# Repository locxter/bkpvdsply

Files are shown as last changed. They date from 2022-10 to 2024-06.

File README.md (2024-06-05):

# bkpvdsply

## Overview

> This project is **DEPRECATED**, therefore might not be on par with my current coding standards and will not receive any updates now or in the future. Please use my [next generation version (BikeBeamer)](https://github.com/BikeBeamer/BikeBeamer) instead.

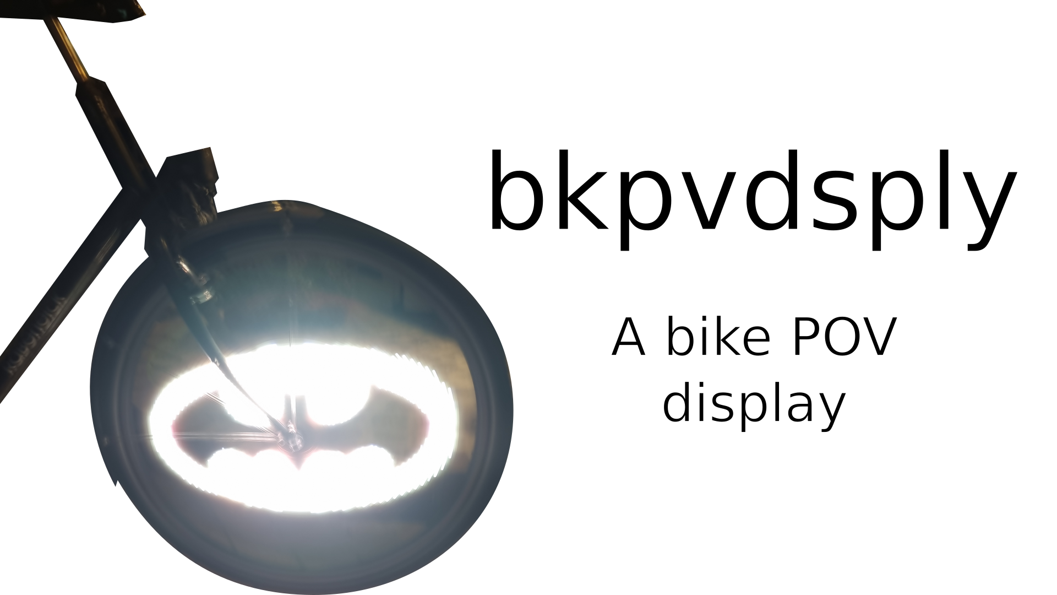
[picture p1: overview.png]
Overview image


This is a bike POV display using readily available parts.

## Dependencies

I generally try to minimize dependencies, but I'm a one man crew and can therefore only support Debian-based Linux distributions as I'm running one myself. Anyway, you need to have the following packages installed for everything to work properly:

- Arduino IDE as a way to compile the Arduino code. Install it with `sudo apt install arduino`.
- Arduino ESP32 LittleFS uploader for uploading the data. Install it via the [installation guide](https://github.com/lorol/arduino-esp32fs-plugin).
- Adafruit NeoPixel library for controlling the LEDs. Install it via the integrated library manager.
- MPU6050_tockn library for communicating with the gyroscope. Install it via the integrated library manager.

## How to build it

This project is relatively straight forward as it mainly consists of an ESP32, an LED strip that's slit into four segments, a MPU-6050 and an USB power bank all housed in 3D printed enclosures and mounted with cable ties. For inspiration take a look at the mounting and assembly image as well as wiring diagram down below:

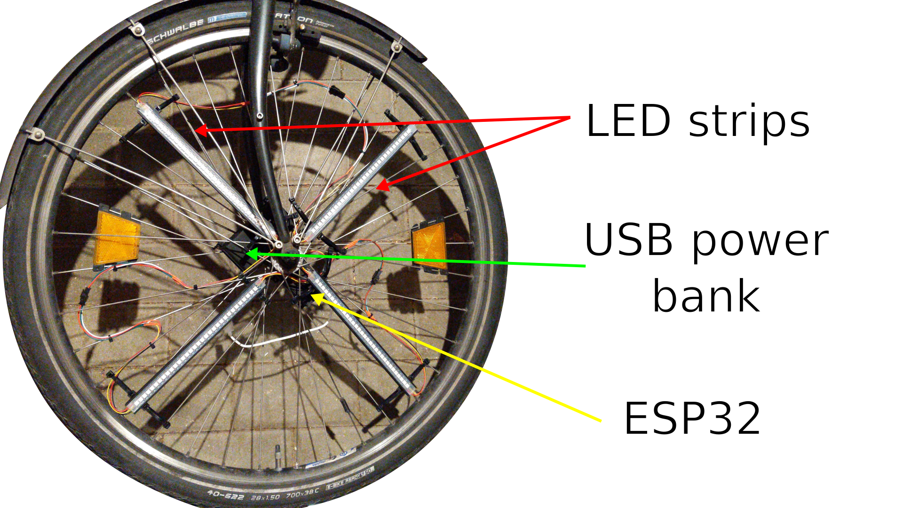
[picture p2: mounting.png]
Mounting image


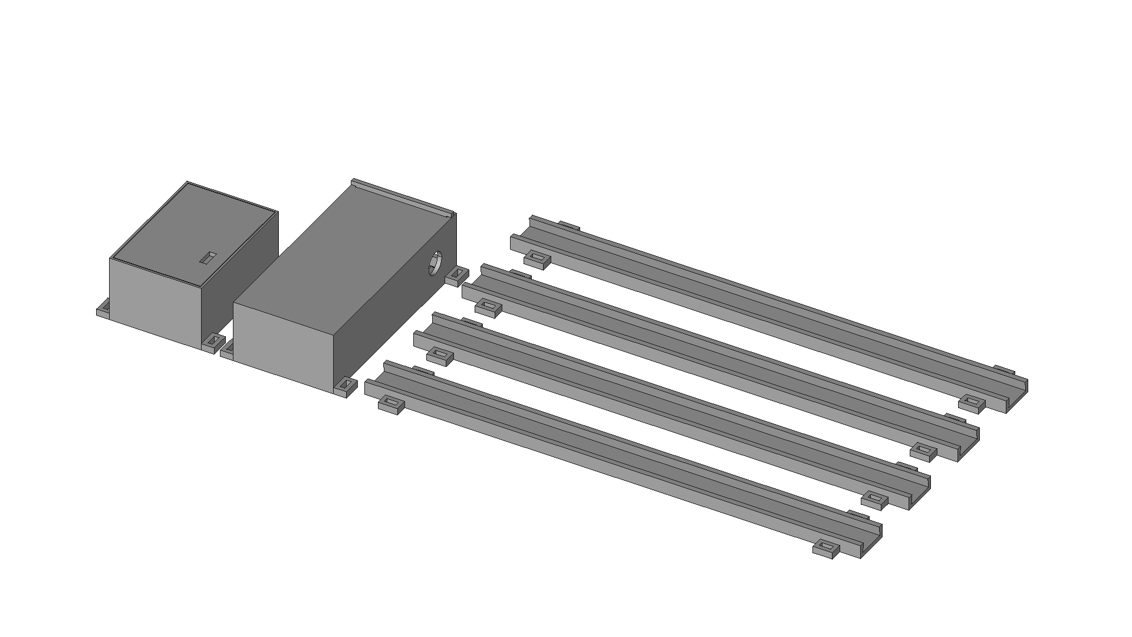
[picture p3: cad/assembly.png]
Assembly image


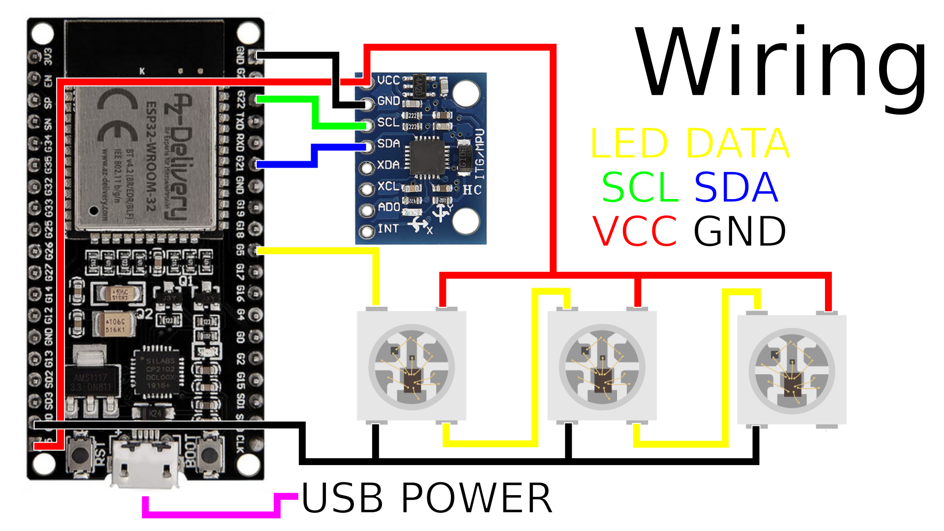
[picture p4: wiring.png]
Wiring diagram


Below is a full bill of materials with German sources for all non-printable parts:

| Quantity: | Item: | Source: |
| --- | --- | --- |
| 1 | ESP32 | [Amazon](https://www.amazon.de/AZDelivery-NodeMCU-Development-Nachfolgermodell-ESP8266/dp/B074RGW2VQ) |
| 1 | LED strip | [Amazon](https://www.amazon.de/CHINLY-Individuell-adressierbar-Traumfarbe-Wasserdicht/dp/B07TLHHJ75) |
| 8 | JST SM 3 pin connectors | [Amazon](https://www.amazon.de/YIXISI-M%C3%A4nnlichen-Weiblichen-Steckverbinder-Elektrisch/dp/B08JV8TJ9N) |
| 1 | MPU-6050 | [Amazon](https://www.amazon.de/AZDelivery-MPU-6050-3-Achsen-Gyroskop-Beschleunigungssensor-Arduino/dp/B07TKLYBD6) |
| 1 | USB power bank | [Amazon](https://www.amazon.de/dp/B01N1UX5JR) |
| 1 | Cable ties | [Amazon](https://www.amazon.de/Kabelbinder-Rscolila-Hochleistungs-Kabelmanagement-300mmx5mm/dp/B08ZC7PBSD) |

## How to use it

1. Flash the sketch with the following settings:
    - `Arduino Runs On: Core 0`
    - `Events Run On: Core 1`
    - `Partition Scheme: No OTA (1MB APP/3MB SPIFFS)`
2. Upload the additional files via the Arduino ESP32 LittleFS uploader.
3. After turning on bkpvdsply, give the ESP roughly half a minute to boot up.
4. Connect to the Wi-Fi network `bkpvdsply`, open any webpage (or `192.168.0.1` if the local DNS server doesn't work) and upload an image (examples are in the `images` folder).
5. Then just hop on your bike and enjoy the glory of POV displays.

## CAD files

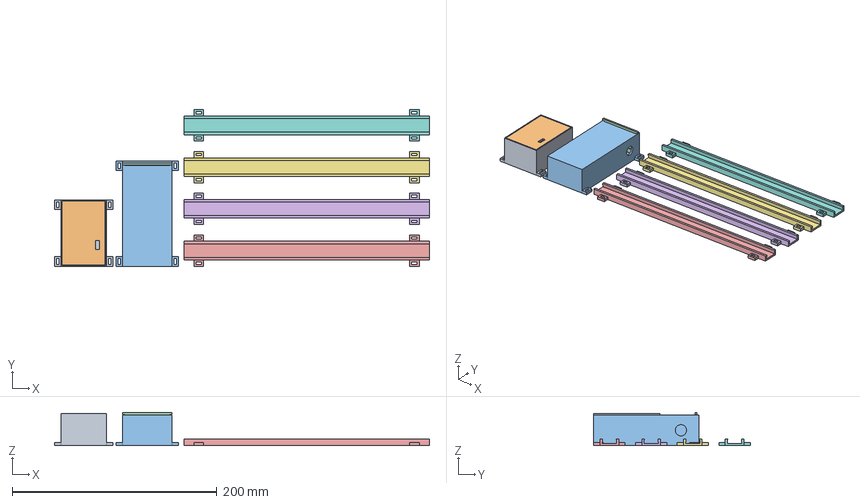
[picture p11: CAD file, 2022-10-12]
cad/assembly.FCStd
366.2 x 153.0 x 32.5 mm
control-board-mount-base_001
control-board-mount-top_001
power-bank-mount-base_001
power-bank-mount-insert_001
led-strip-mount_001
led-strip-mount_002
led-strip-mount_003
led-strip-mount_004

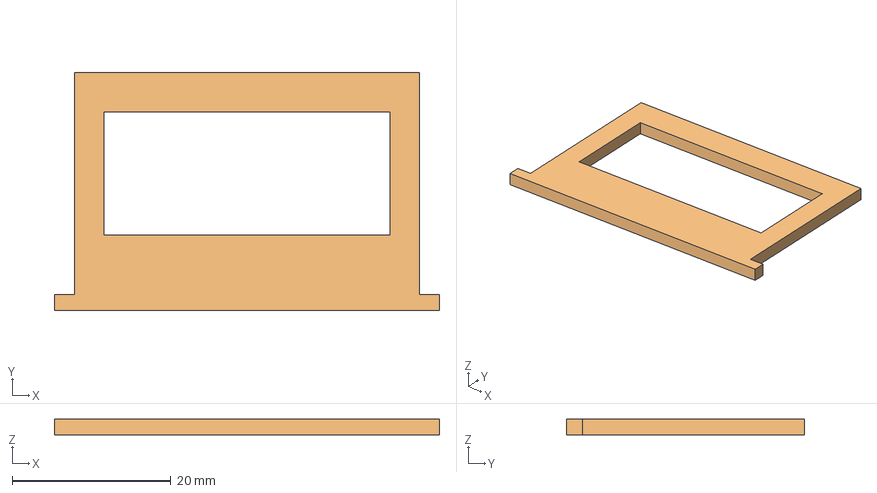
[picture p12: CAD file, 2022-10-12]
cad/power-bank-mount-insert.FCStd
48.5 x 30.0 x 2.00 mm
Body (Meshed)

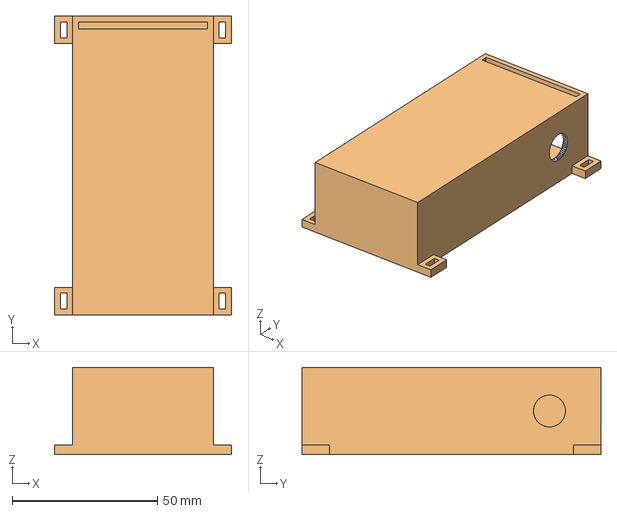
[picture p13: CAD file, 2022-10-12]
cad/power-bank-mount-base.FCStd
61.0 x 103.0 x 30.0 mm
Body (Meshed)

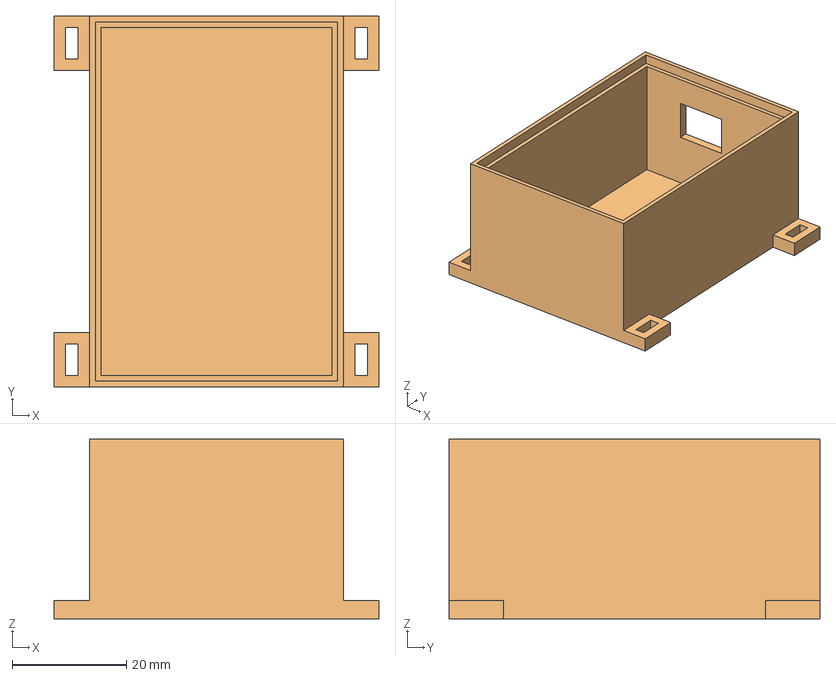
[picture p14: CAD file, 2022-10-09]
cad/control-board-mount-base.FCStd
57.0 x 65.0 x 31.5 mm
Body (Meshed)

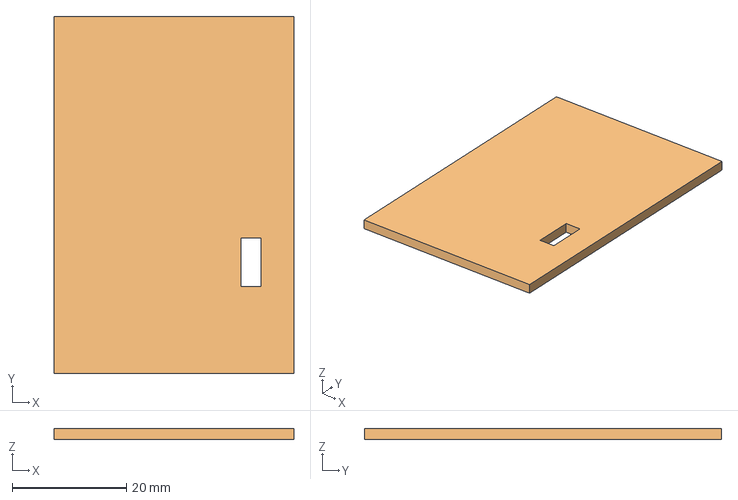
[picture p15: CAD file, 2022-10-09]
cad/control-board-mount-top.FCStd
42.0 x 62.5 x 2.00 mm
Body (Meshed)

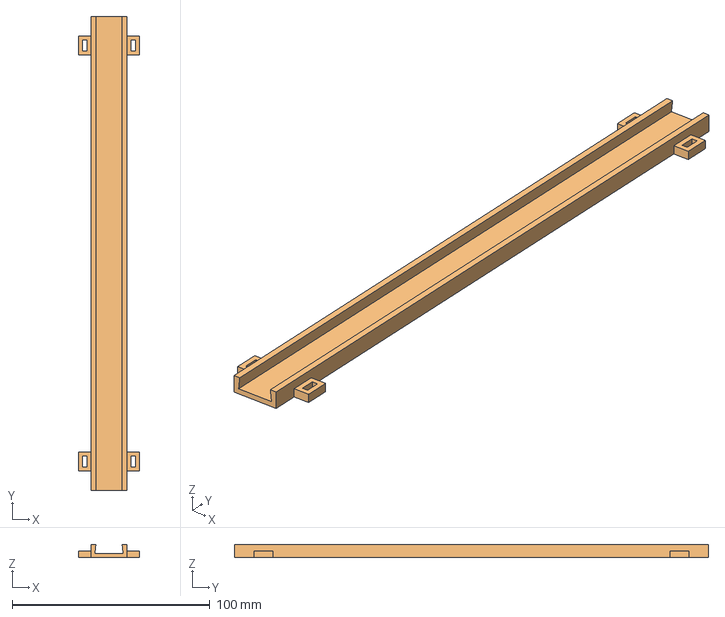
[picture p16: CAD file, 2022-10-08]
cad/led-strip-mount.FCStd
30.8 x 240.0 x 6.50 mm
Body (Meshed)

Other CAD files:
cad/control-board-mount-base.stl
cad/control-board-mount-top.stl
cad/led-strip-mount.stl
cad/power-bank-mount-base.stl
cad/power-bank-mount-insert.stl

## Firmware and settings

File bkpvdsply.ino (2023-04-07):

#include <Adafruit_NeoPixel.h>
#include <DNSServer.h>
#include <LittleFS.h>
#include <MPU6050_tockn.h>
#include <WebServer.h>
#include <WiFi.h>
#include <WiFiClient.h>
#include <Wire.h>
#include <uri/UriBraces.h>

// LED and WiFi related constants
const int NEOPIXELS_PIN = 5;
const int STORAGE_SLOT_COUNT = 8;
const int LED_COUNT = 32;
const char* SSID = "bkpvdsply";
const char* WIFI_PASSWORD = "bkpvdsply";
const IPAddress IP(192, 168, 0, 1);

// MPU, NeoPixel and server objects
MPU6050 mpu(Wire);
Adafruit_NeoPixel neopixels(LED_COUNT * 4, NEOPIXELS_PIN, NEO_GRB + NEO_KHZ800);
DNSServer dns;
WebServer server(80);

// Other variables
byte images[2][360 * LED_COUNT][3];
unsigned long currentMicros = 0;
unsigned long revolutionPeriod = 0;
unsigned long lastRotation = 0;
unsigned long lastSlotChange = 0;
unsigned long animationInterval = 1000000;
int brightness = 128;
int displayMode = 0;
int currentMemorySlot = 0;
int angle = 0;
int virtualAngle = 0;
int lastVirtualAngle = -1;
bool isReceiving = false;
bool isPaused = true;

// Function to load the settings from storage into RAM
void loadSettings();

// Function to save the settings from RAM into storage
void saveSettings();

// Function to load an image from storage into RAM
void loadImage(int storageSlot, int memorySlot);

// Setup function
void setup() {
    // Initialize MPU
    Wire.begin();
    mpu.begin();
    mpu.calcGyroOffsets();
    // Initialize filesystem and memory
    LittleFS.begin();
    loadSettings();
    if (displayMode < STORAGE_SLOT_COUNT) {
        loadImage(displayMode, 0);
    } else {
        loadImage(displayMode - STORAGE_SLOT_COUNT, 0);
        loadImage((displayMode - (STORAGE_SLOT_COUNT - 1)) % STORAGE_SLOT_COUNT, 1);
    }
    // Initiliaze NeoPixels
    neopixels.begin();
    neopixels.setBrightness(brightness);
    neopixels.clear();
    neopixels.show();
    // Initialize WiFi network
    WiFi.mode(WIFI_AP);
    WiFi.softAPConfig(IP, IP, IPAddress(255, 255, 255, 0));
    WiFi.softAP(SSID, WIFI_PASSWORD);
    // Initialize DNS
    dns.start(53, "*", IP);
    // Initialize web server
    server.enableCORS(true);
    server.on("/", HTTP_GET, [&]() {
        File file = LittleFS.open("/index.html", "r");
        String content;
        while (file.available()) {
            content += (char) file.read();
        }
        file.close();
        server.send(200, "text/html", content);
    });
    server.on("/", HTTP_POST, [&]() {
        // Check for necessary arguments
        bool hasSettingsArgs =
            server.hasArg("brightness") && server.hasArg("display-mode") && server.hasArg("animation-interval");
        bool hasImageArgs = server.hasArg("slot") && server.hasArg("angle");
        for (int i = 0; i < LED_COUNT; i++) {
            if (!hasImageArgs) {
                break;
            }
            hasImageArgs = server.hasArg("led-" + String(i) + "-r");
        }
        for (int i = 0; i < LED_COUNT; i++) {
            if (!hasImageArgs) {
                break;
            }
            hasImageArgs = server.hasArg("led-" + String(i) + "-g");
        }
        for (int i = 0; i < LED_COUNT; i++) {
            if (!hasImageArgs) {
                break;
            }
            hasImageArgs = server.hasArg("led-" + String(i) + "-b");
        }
        // Extract and store the received data
        if (hasSettingsArgs) {
            isReceiving = true;
            neopixels.clear();
            neopixels.show();
            brightness = server.arg("brightness").toInt();
            displayMode = server.arg("display-mode").toInt();
            animationInterval = server.arg("animation-interval").toInt();
            neopixels.setBrightness(brightness);
            neopixels.show();
            if (displayMode < STORAGE_SLOT_COUNT) {
                loadImage(displayMode, currentMemorySlot);
            } else {
                loadImage(displayMode - STORAGE_SLOT_COUNT, 0);
                loadImage((displayMode - (STORAGE_SLOT_COUNT - 1)) % STORAGE_SLOT_COUNT, 1);
            }
            saveSettings();
            isReceiving = false;
            server.send(200);
        } else if (hasImageArgs) {
            int storageSlot = server.arg("slot").toInt();
            int memorySlot = -1;
            int angle = server.arg("angle").toInt();
            String filename = "/data/image-" + String(storageSlot) + ".csv";
            File file;
            if (angle == 0) {
                isReceiving = true;
                neopixels.clear();
                neopixels.show();
                file = LittleFS.open(filename, "w");
                file.print("R:, G:, B:\n");
            } else {
                file = LittleFS.open(filename, "a");
            }
            if (storageSlot == displayMode) {
                memorySlot = currentMemorySlot;
            } else if (storageSlot == displayMode - STORAGE_SLOT_COUNT) {
                memorySlot = 0;
            } else if (storageSlot == (displayMode - (STORAGE_SLOT_COUNT - 1)) % STORAGE_SLOT_COUNT) {
                memorySlot = 1;
            }
            for (int i = 0; i < LED_COUNT; i++) {
                byte r = server.arg("led-" + String(i) + "-r").toInt();
                byte g = server.arg("led-" + String(i) + "-g").toInt();
                byte b = server.arg("led-" + String(i) + "-b").toInt();
                if (memorySlot != -1) {
                    images[memorySlot][(angle * LED_COUNT) + i][0] = r;
                    images[memorySlot][(angle * LED_COUNT) + i][1] = g;
                    images[memorySlot][(angle * LED_COUNT) + i][2] = b;
                }
                file.print(String(r) + ", " + String(g) + ", " + String(b) + "\n");
            }
            file.close();
            if (angle == 359) {
                isReceiving = false;
            }
            server.send(200);
        } else {
            server.send(404, "text/plain", "Invalid request");
        }
    });
    server.serveStatic("/data/image-0.csv", LittleFS, "/data/image-0.csv");
    server.serveStatic("/data/image-1.csv", LittleFS, "/data/image-1.csv");
    server.serveStatic("/data/image-2.csv", LittleFS, "/data/image-2.csv");
    server.serveStatic("/data/image-3.csv", LittleFS, "/data/image-3.csv");
    server.serveStatic("/data/image-4.csv", LittleFS, "/data/image-4.csv");
    server.serveStatic("/data/image-5.csv", LittleFS, "/data/image-5.csv");
    server.serveStatic("/data/image-6.csv", LittleFS, "/data/image-6.csv");
    server.serveStatic("/data/image-7.csv", LittleFS, "/data/image-7.csv");
    server.serveStatic("/data/settings.csv", LittleFS, "/data/settings.csv");
    server.serveStatic("/scripts/index.js", LittleFS, "/scripts/index.js");
    server.serveStatic("/styles/dark.min.css", LittleFS, "/styles/dark.min.css");
    server.onNotFound([&]() {
        server.send(404, "text/plain", "Resource not found");
    });
    server.begin();
    lastRotation = micros();
    lastSlotChange = micros();
}

// Main function
void loop() {
    if (!isReceiving) {
        mpu.update();
        angle = ((int) round(mpu.getAccAngleX()) + 360) % 360;
        currentMicros = micros();
        // Calculate revolution period and update other data on every rotation when the user is pedalling
        if ((angle >= 353 || angle <= 7) && currentMicros - lastRotation >= 150000 &&
            currentMicros - lastRotation <= 1500000) {
            if (isPaused) {
                isPaused = false;
            }
            if (displayMode >= STORAGE_SLOT_COUNT && currentMicros - lastSlotChange > animationInterval) {
                currentMemorySlot = (currentMemorySlot + 1) % 2;
                lastSlotChange = currentMicros;
            }
            revolutionPeriod = currentMicros - lastRotation;
            lastRotation = currentMicros;
            virtualAngle = 0;
            lastVirtualAngle = -1;
        }
        // Pause display when user stops pedalling
        if (currentMicros - lastRotation > 1500000) {
            if (!isPaused) {
                neopixels.clear();
                neopixels.show();
                isPaused = true;
            }
            lastRotation = currentMicros;
        }
        if (!isPaused) {
            virtualAngle = (int) round((currentMicros - lastRotation) / (revolutionPeriod / 360.0)) % 360;
            // Display an angle of the image
            if (virtualAngle != lastVirtualAngle) {
                for (int i = 0; i < LED_COUNT; i++) {
                    byte r = images[currentMemorySlot][(virtualAngle * LED_COUNT) + i][0];
                    byte g = images[currentMemorySlot][(virtualAngle * LED_COUNT) + i][1];
                    byte b = images[currentMemorySlot][(virtualAngle * LED_COUNT) + i][2];
                    neopixels.setPixelColor(i, neopixels.Color(r, g, b));
                    r = images[currentMemorySlot][(((virtualAngle + 90) % 360) * LED_COUNT) + i][0];
                    g = images[currentMemorySlot][(((virtualAngle + 90) % 360) * LED_COUNT) + i][1];
                    b = images[currentMemorySlot][(((virtualAngle + 90) % 360) * LED_COUNT) + i][2];
                    neopixels.setPixelColor(i + LED_COUNT, neopixels.Color(r, g, b));
                    r = images[currentMemorySlot][(((virtualAngle + 180) % 360) * LED_COUNT) + i][0];
                    g = images[currentMemorySlot][(((virtualAngle + 180) % 360) * LED_COUNT) + i][1];
                    b = images[currentMemorySlot][(((virtualAngle + 180) % 360) * LED_COUNT) + i][2];
                    neopixels.setPixelColor(i + (LED_COUNT * 2), neopixels.Color(r, g, b));
                    r = images[currentMemorySlot][(((virtualAngle + 270) % 360) * LED_COUNT) + i][0];
                    g = images[currentMemorySlot][(((virtualAngle + 270) % 360) * LED_COUNT) + i][1];
                    b = images[currentMemorySlot][(((virtualAngle + 270) % 360) * LED_COUNT) + i][2];
                    neopixels.setPixelColor(i + (LED_COUNT * 3), neopixels.Color(r, g, b));
                }
                neopixels.show();
                lastVirtualAngle = virtualAngle;
            }
        }
    }
    dns.processNextRequest();
    server.handleClient();
}

// Function to load the settings from storage into RAM
void loadSettings() {
    File file = LittleFS.open("/data/settings.csv", "r");
    while (file.available()) {
        String line = file.readStringUntil('\n');
        String key = line.substring(0, line.indexOf(','));
        line.remove(0, line.indexOf(',') + 2);
        unsigned long value = line.toInt();
        if (key == "brightness") {
            brightness = value;
        } else if (key == "display-mode") {
            displayMode = value;
        } else if (key == "animation-interval") {
            animationInterval = value;
        }
    }
    file.close();
}

// Function to save the settings from RAM into storage
void saveSettings() {
    File file = LittleFS.open("/data/settings.csv", "w");
    file.print("Key:, Value:\n");
    file.print("brightness, " + String(brightness) + "\n");
    file.print("display-mode, " + String(displayMode) + "\n");
    file.print("animation-interval, " + String(animationInterval) + "\n");
    file.close();
}

// Function to load an image from storage into RAM
void loadImage(int storageSlot, int memorySlot) {
    String filename = "/data/image-" + String(storageSlot) + ".csv";
    File file;
    // Clear the image
    for (int i = 0; i < 360 * LED_COUNT; i++) {
        images[memorySlot][i][0] = 0;
        images[memorySlot][i][1] = 0;
        images[memorySlot][i][2] = 0;
    }
    // Load the new image
    file = LittleFS.open(filename, "r");
    for (int i = -1; i < 360 * LED_COUNT; i++) {
        String line;
        if (!file.available()) {
            break;
        }
        line = file.readStringUntil('\n');
        if (i > -1) {
            images[memorySlot][i][0] = line.substring(0, line.indexOf(',')).toInt();
            line.remove(0, line.indexOf(',') + 1);
            images[memorySlot][i][1] = line.substring(0, line.indexOf(',')).toInt();
            line.remove(0, line.indexOf(',') + 1);
            images[memorySlot][i][2] = line.toInt();
        }
    }
    file.close();
}

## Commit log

2022-09-30 Uploaded already existing files.
    [image.csv]
2022-10-07 Started working on the CAD design.
    [hub-replica.FCStd, hub-replica.stl, led-strip-mount.FCStd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]
2022-10-07 Switched to an ESP32 and implemented the basic data storage.
2022-10-08 Added basic display capabilities.
    [led-strip-mount.FCStd, led-strip-mount.stl]
2022-10-09 Designed a control board and power bank mount.
    [assembly.FCStd, control-board-mount-base.FCStd, control-board-mount-base.stl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]
2022-10-11 Adapted the power bank mount to the actual dimensions.
    [assembly.FCStd, hub-replica.FCStd, hub-replica.stl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]
2022-10-12 Minor tweak to the power bank mount.
    [assembly.FCStd, power-bank-mount-base.FCStd, power-bank-mount-base.stl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]
2022-10-16 Switched back to good old Linux Mint.
2022-10-18 Added support for all 4 LED strips.
    [image.csv]
2022-11-07 Reworked the overview image and added additional assembly information.
2022-11-15 Implemented initial animation support.
    [image-0.csv, image-1.csv, settings.csv]
2022-11-24 Added additional storage slots for images.
    [image-2.csv, image-3.csv, image-4.csv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]
2024-04-26 Added a wiring diagram.
2024-04-26 Fixed a small mistake in the wiring diagram.
